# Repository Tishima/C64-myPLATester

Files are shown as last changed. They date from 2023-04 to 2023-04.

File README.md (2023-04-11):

# C64 myPLATester shield - PLA 906114-01
The myPLATester shield is a Arduino Mega shield , to test the C64 PLA 906114-01 or his clones like the GAL PAL.
It check all output vectors  via all input vectors and shows the result with a LED or serial output

Its based on the work from AC Lovell - ACs 8-Bit Zone
for more information look at his Video
https://www.youtube.com/watch?v=Yru8bx_IqN8
           
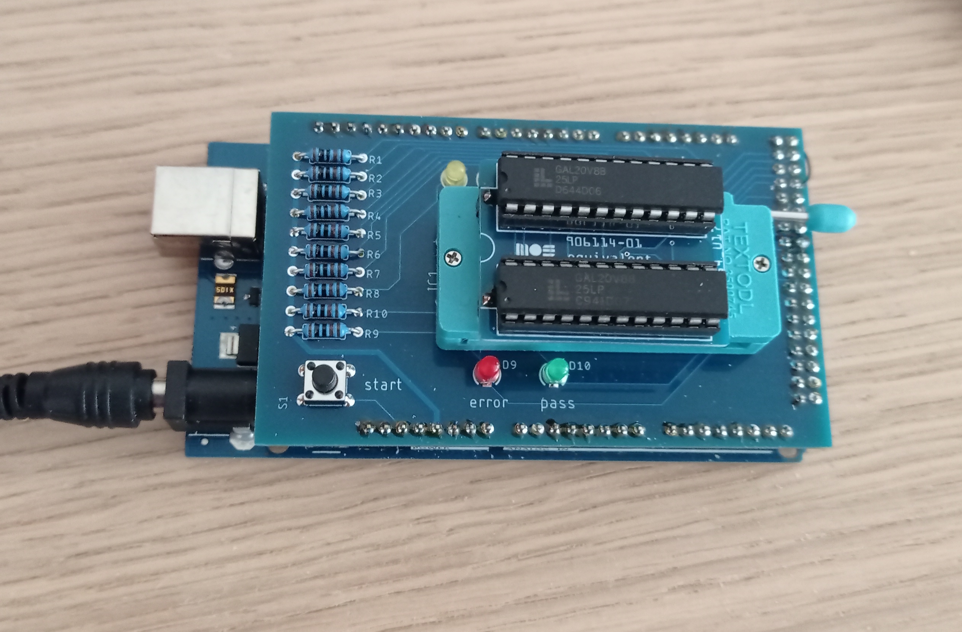
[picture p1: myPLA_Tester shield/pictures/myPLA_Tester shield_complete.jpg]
C64 myPLATester shield


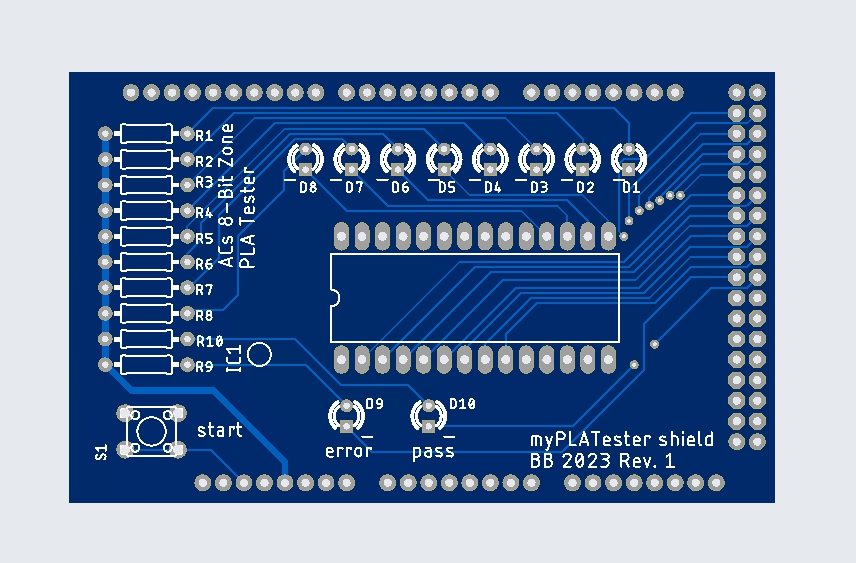
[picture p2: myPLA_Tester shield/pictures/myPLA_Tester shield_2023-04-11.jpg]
C64 myPLATester shield PCB

         
This repository contains all eagle files, gerber file, BOM, schematics, a little adjusted Arduino source code for my shield hardware, based on ACs code

Depending on where the parts and pcbs are purchased, the price for the complete shield is around 20€ (2023), without Arduino Mega and power supply
I built this project to find a issue with the GAL PLA from https://www.freepascal.org/~daniel/c64pla/, but the problem was only a wrong programming failure of my site.

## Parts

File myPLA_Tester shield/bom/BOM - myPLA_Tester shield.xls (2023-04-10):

Qty | Designator | Value | Distributor | Discription | Order Number | Price | PriceTotal | Qty count | Price count
10 | R1-R10 | 1k | Reichelt | METALL 1,00K Widerstand, Metallschicht, 1,00 kOhm, 0207, 0,6 W, 1% | METALL 1,00K | 0.11 € | 1.10 € | 10 | 1.10 €
8 | D1-D8 | LED ye | Reichelt | KBT L-7104YD LED, 3 mm, bedrahtet, gelb, 15 mcd, 40° | KBT L-7104YD | 0.15 € | 1.20 € | 8 | 1.20 €
1 | D9 | LED rd | Reichelt | KBT L-7104HD LED, 3 mm, bedrahtet, rot, 3 mcd, 40° | KBT L-7104HD | 0.14 € | 0.14 € | 1 | 0.14 €
1 | D10 | LED gr | Reichelt | KBT L-7104SGD LED, 3 mm, bedrahtet, grün, 40 mcd, 40° | KBT L-7104SGD | 0.16 € | 0.16 € | 1 | 0.16 €
2 | X1-X6 |  | Reichelt | MPE 087-1-050 Stiftleisten 2,54 mm, 1X50, gerade | MPE 087-1-050 | 0.96 € | 1.92 € | 2 | 1.92 €
1 | X7 |  | Reichelt | SL 2X36G 2,54 2x36pol.-Stiftleiste, gerade, RM 2,54 | SL 2X36G 2,54 | 0.33 € | 0.33 € | 1 | 0.33 €
1 | S1 | 3301 | Reichelt | TASTER 3301 Kurzhubtaster 6x6mm, Höhe: 4,3mm, 12V, vertikal | TASTER 3301 | 0.16 € | 0.16 € | 1 | 0.16 €
1 | IC1 |  | TME | Sockel: integrierte Schaltkreise; ZIF; DIP28; 7,62/15,24mm; THT | DS1043-280G | 4.50 € | 4.50 € | 1 | 4.50 €
1 | Arduino Mega |  | Amazon | ELEGOO Mega-R3 Mikrocontroller Board |  | 19.54 € | 19.54 € | 1 | 19.54 €
1 | PSU |  | Amazon | Netzteil für Arduino Mega, Ladegerät 9V 500mA 1000mA, Ladekabel AC DC 5,5X2,1mm |  | 9.99 € | 9.99 € | 1 | 9.99 €
 | count | 1
 | price piece | 39.04 €
 | price total | 39.04 €

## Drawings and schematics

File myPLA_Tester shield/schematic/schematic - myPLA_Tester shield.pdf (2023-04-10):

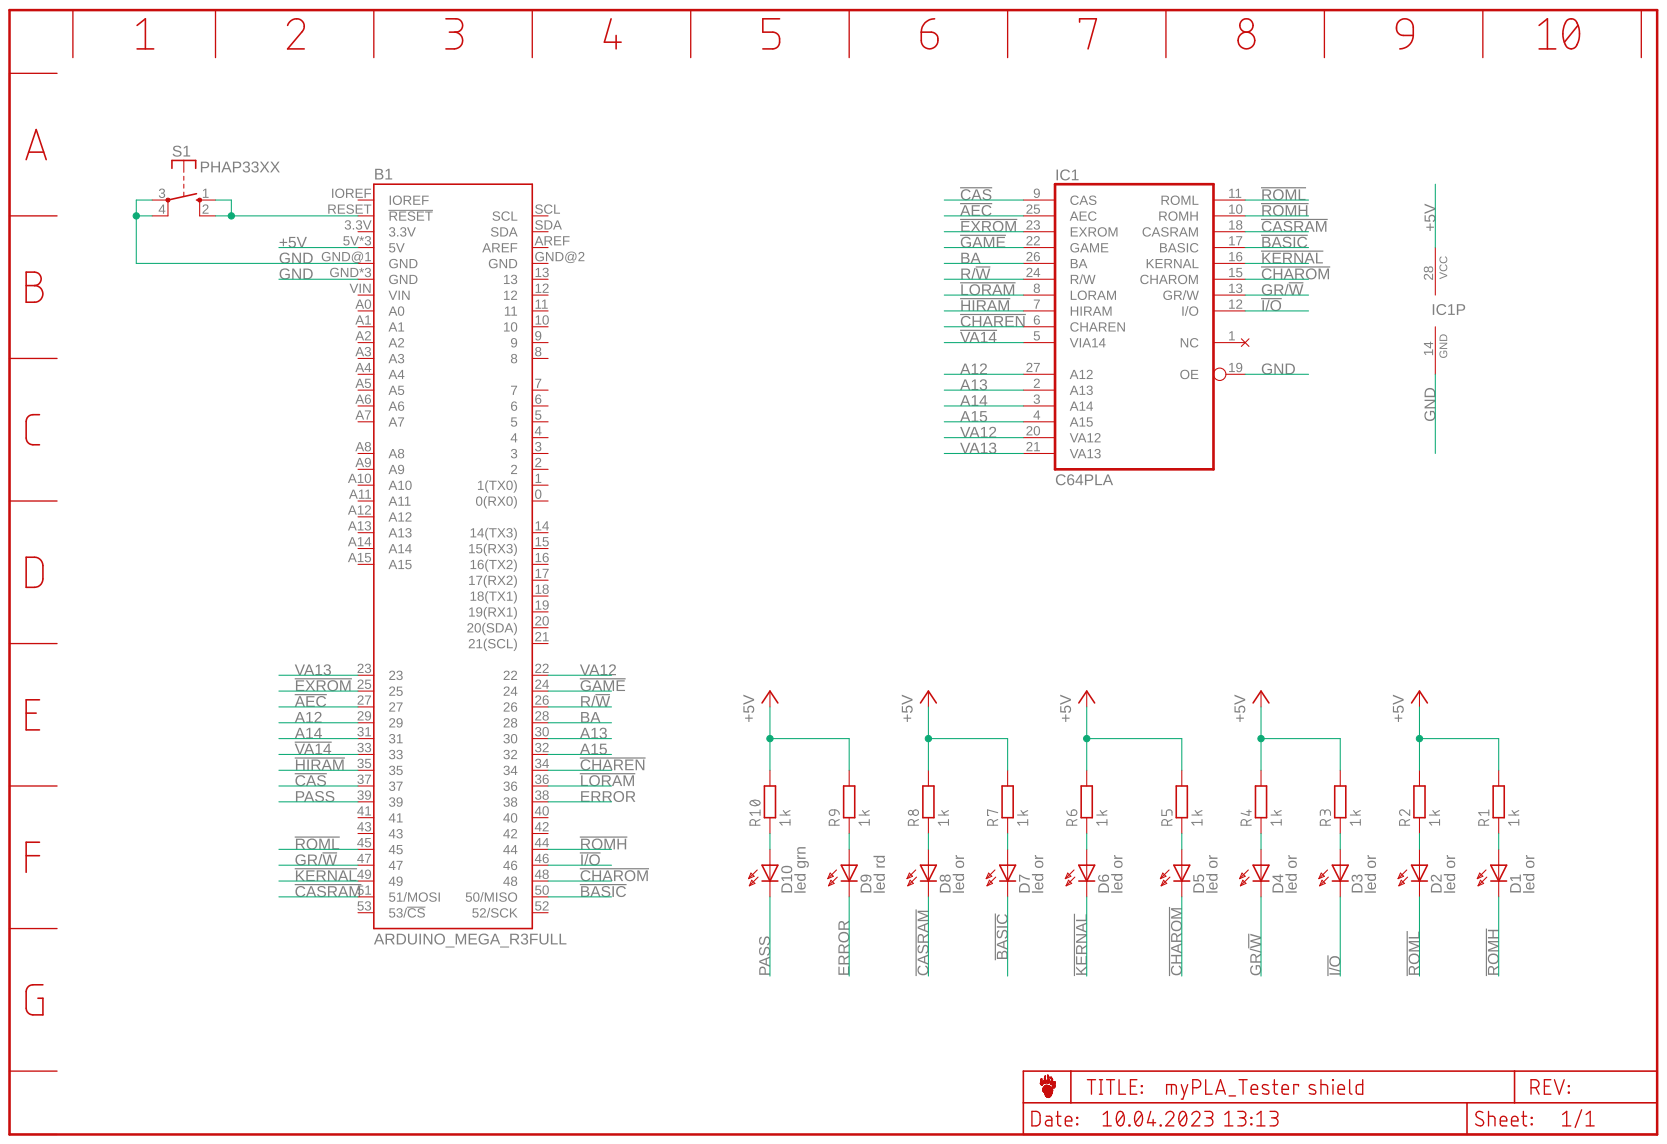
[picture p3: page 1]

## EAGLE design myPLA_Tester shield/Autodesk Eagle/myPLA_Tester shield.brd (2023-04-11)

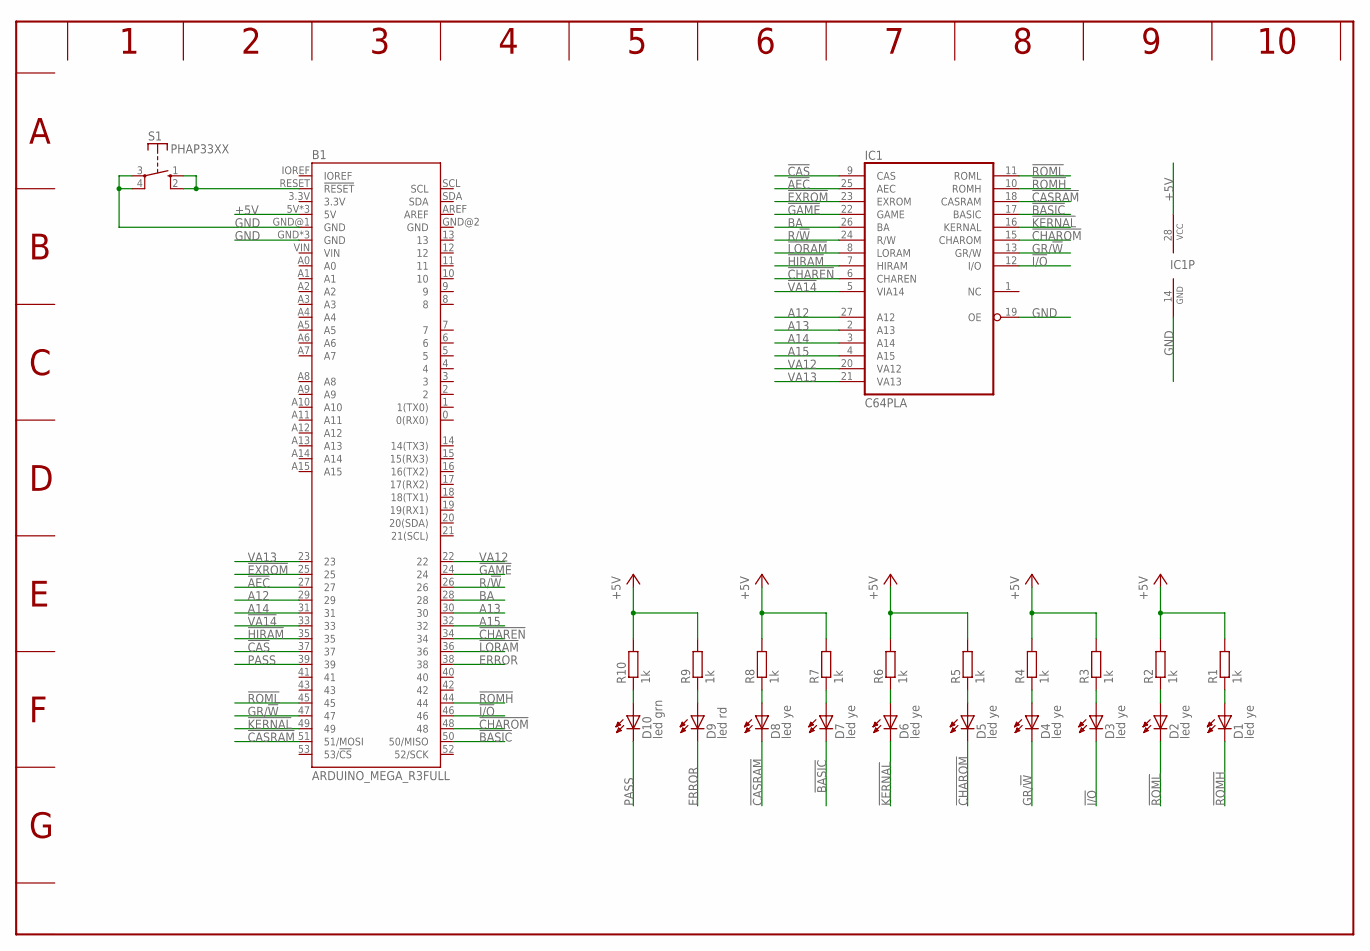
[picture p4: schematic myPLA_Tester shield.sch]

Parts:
B1: ARDUINO_MEGA_R3FULL; ARDUINO_MEGA_NO_SILK
D1, D2, D3, D4, D5, D6, D7, D8: led ye; LED3MM
D9: led rd; LED3MM
D10: led grn; LED3MM
IC1: C64PLA; DIL28
R1, R2, R3, R4, R5, R6, R7, R8, R9, R10: 1k; 0207/10
S1: PHAP33XX

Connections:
!AEC: B1.27, IC1.25 (AEC)
!BASIC: B1.50 (50/MISO), D7.K (C), IC1.17 (BASIC)
!CAS: B1.37, IC1.9 (CAS)
!CASRAM: B1.51 (51/MOSI), D8.K (C), IC1.18 (CASRAM)
!CHAREN: B1.34, IC1.6 (CHAREN)
!CHAROM: B1.48, D5.K (C), IC1.15 (CHAROM)
!EXROM: B1.25, IC1.23 (EXROM)
!GAME: B1.24, IC1.22 (GAME)
!HIRAM: B1.35, IC1.7 (HIRAM)
!I/O: B1.46, D3.K (C), IC1.12 (I/O)
!KERNAL: B1.49, D6.K (C), IC1.16 (KERNAL)
!LORAM: B1.36, IC1.8 (LORAM)
!ROMH: B1.44, D1.K (C), IC1.10 (ROMH)
!ROML: B1.45, D2.K (C), IC1.11 (ROML)
!VA14: B1.33, IC1.5 (VIA14)
+5V: B1.5V, B1.5V@1 (5V), B1.5V@2 (5V), IC1.28 (VCC), R1.2, R2.2, R3.2, R4.2, R5.2, R6.2, R7.2, R8.2, R9.2, R10.2
A12: B1.29, IC1.27 (A12)
A13: B1.30, IC1.2 (A13)
A14: B1.31, IC1.3 (A14)
A15: B1.32, IC1.4 (A15)
BA: B1.28, IC1.26 (BA)
ERROR: B1.38, D9.K (C)
GND: B1.GND, B1.GND@1 (GND), B1.GND@3 (GND), B1.GND@4 (GND), IC1.14 (GND), IC1.19 (OE), S1.3, S1.4
GR/!W: B1.47, D4.K (C), IC1.13 (GR/W)
unnamed: D2.A, R2.1
unnamed: D1.A, R1.1
unnamed: D10.A, R10.1
unnamed: D9.A, R9.1
unnamed: D8.A, R8.1
unnamed: D7.A, R7.1
unnamed: D6.A, R6.1
unnamed: D5.A, R5.1
unnamed: D4.A, R4.1
unnamed: D3.A, R3.1
unnamed: B1.RESET (!RESET), S1.1 (S), S1.2 (S)
PASS: B1.39, D10.K (C)
R/!W: B1.26, IC1.24 (R/W)
VA12: B1.22, IC1.20 (VA12)
VA13: B1.23, IC1.21 (VA13)

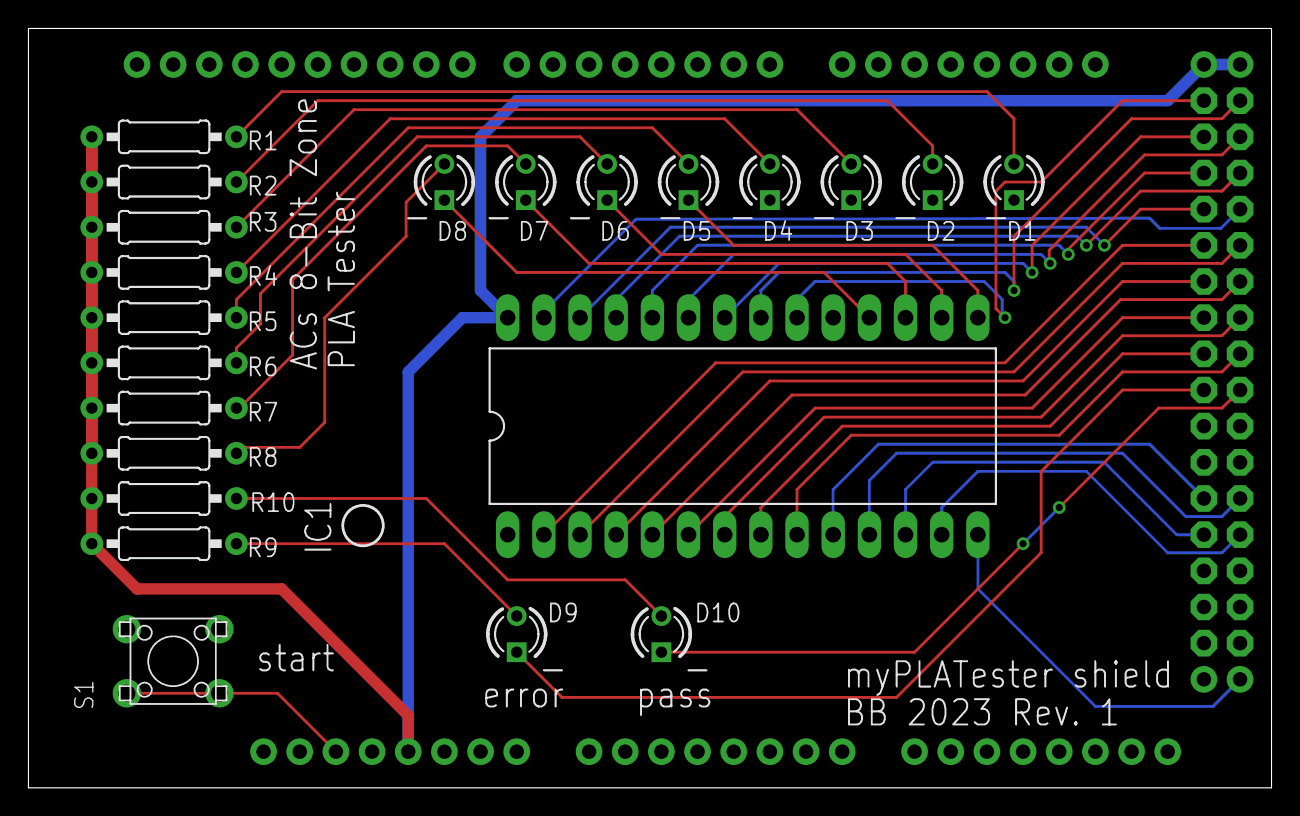
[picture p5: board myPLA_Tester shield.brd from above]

Board: 4 copper layers, 87.3 x 53.3 mm, 23 parts (0 on the bottom side), 39 nets.

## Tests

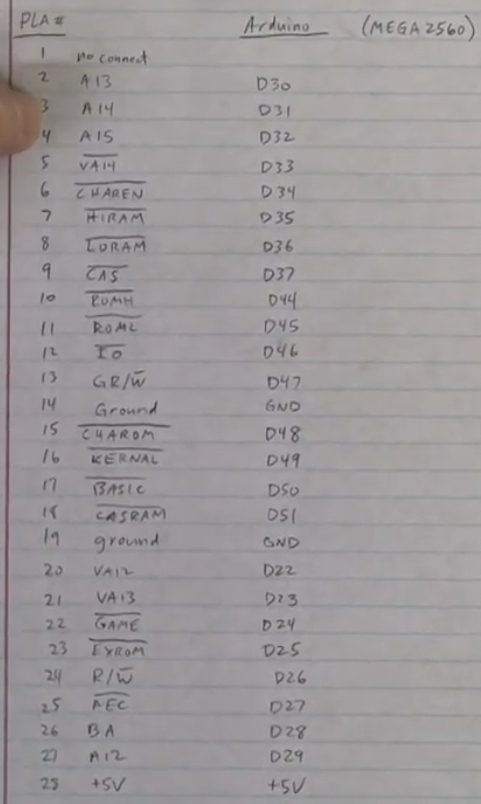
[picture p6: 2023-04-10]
myPLA_Tester shield/basics/PLATester.jpg

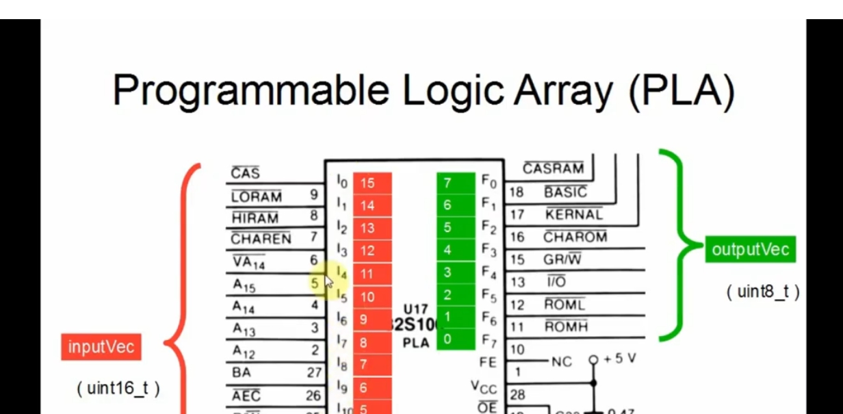
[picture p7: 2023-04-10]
myPLA_Tester shield/basics/PLATester_2.jpg

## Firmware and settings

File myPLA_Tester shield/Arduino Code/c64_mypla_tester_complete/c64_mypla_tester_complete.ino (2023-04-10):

// based on the work from AC Lovell - ACs 8-Bit Zone 10/2020
// https://www.youtube.com/watch?v=Yru8bx_IqN8
//
// some little improvements for the PLA Tester shield by Bjoern Buettner 04/2023


const bool VERBOSE = false;

uint8_t   outputVec;    // PLA outputs
uint8_t   expectedVec;  // expected PLA outputs, calculated
uint16_t  inputVec;     // PLA inputs
uint16_t  shiftReg;

char    outbuffer[120];
char    inbuffer[120];
//String  str;
//char    ch;

const uint16_t MASK[32] = {
  0x6734, 0x2734, 0x273c, 0x37b4,
  0x57b4, 0x37bc, 0x0827, 0x082f, 
  0x87b0, 0x37f4, 0x37b4, 0x57f4, 
  0x57b4, 0x37fc, 0x37bc, 0x57fc, 
  0x57bc, 0x07fc, 0x07bc, 0x6738, 
  0x072c, 0x273c, 0x072c, 0x002f, 
  0x068c, 0x070c, 0x060c, 0x070c, 
  0x078c, 0x8000, 0x8000, 0x87b0
};

const uint16_t COMP[32] = {
  0x6514, 0x2714, 0x2710, 0x2694,
  0x4694, 0x2690, 0x0825, 0x0821, 
  0x8680, 0x36d4, 0x3684, 0x56d4, 
  0x5684, 0x36d0, 0x3680, 0x56d0, 
  0x5680, 0x06d8, 0x0688, 0x6410, 
  0x0408, 0x2510, 0x0708, 0x002b, 
  0x0088, 0x0108, 0x0208, 0x0508, 
  0x0608, 0x0000, 0x8000, 0x0680
};

bool pterm[32];
long total;
long passes;

void setup() {
  // put your setup code here, to run once:

  Serial.begin(115200);
  Serial.print("Initializing test pins.\n");

  inputVec = 0xFF;

  // PLA inputs are Arduino outputs
  // We need 16 output pins
  pinMode(22, OUTPUT);
  pinMode(23, OUTPUT);
  pinMode(24, OUTPUT);
  pinMode(25, OUTPUT);
  pinMode(26, OUTPUT);
  pinMode(27, OUTPUT);
  pinMode(28, OUTPUT);
  pinMode(29, OUTPUT);
  pinMode(30, OUTPUT);
  pinMode(31, OUTPUT);
  pinMode(32, OUTPUT);
  pinMode(33, OUTPUT);
  pinMode(34, OUTPUT);
  pinMode(35, OUTPUT);
  pinMode(36, OUTPUT);
  pinMode(37, OUTPUT);

  pinMode(38, OUTPUT);     //error LED
  pinMode(39, OUTPUT);     //passe LED

  digitalWrite(38, HIGH ); // error led off
  digitalWrite(39, HIGH ); // pass led off

  digitalWrite(22, HIGH ); // 
  digitalWrite(23, HIGH ); // 
  digitalWrite(24, HIGH ); // 
  digitalWrite(25, HIGH ); // 
  digitalWrite(26, HIGH ); // 
  digitalWrite(27, HIGH ); // 
  digitalWrite(28, HIGH ); // 
  digitalWrite(29, HIGH ); // 
  digitalWrite(30, HIGH ); // 
  digitalWrite(31, HIGH ); // 
  digitalWrite(32, HIGH ); // 
  digitalWrite(33, HIGH ); // 
  digitalWrite(34, HIGH ); // 
  digitalWrite(35, HIGH ); // 
  digitalWrite(36, HIGH ); // 
  digitalWrite(37, HIGH ); // 

  // PLA outputs are Arduino inputs
  // We need 8 inputs
  outputVec = 0x00;
  pinMode(44, INPUT);
  pinMode(45, INPUT);
  pinMode(46, INPUT);
  pinMode(47, INPUT);
  pinMode(48, INPUT);
  pinMode(49, INPUT);
  pinMode(50, INPUT);
  pinMode(51, INPUT);

  passes = 0;
  total  = 0;
}


void loop() {
  // put your main code here, to run repeatedly:
  int i;
  long v; // needs to reach 65536 without rolling over

  Serial.print("Starting test. This can take up to 1 minute.\n");

  // Loop through 2^16 possible input combinations. 
  // Calculate the product terms.
  for (inputVec=0,v=0; v<65536; v++,inputVec++) {
    shiftReg = inputVec;
    // Transfer values to the pin signals D37:D22
    for (i=0; i<16; i++) {
      if (shiftReg & 0x0001) {
        digitalWrite(22+i, HIGH);
      }
      else {
        digitalWrite(22+i, LOW);
      }
      shiftReg = shiftReg >> 1;
    }
  
    // Calculate the Product terms for the set of inputVec values
    for (i=0; i<32; i++) {
      pterm[i] = ( inputVec & MASK[i] ) == COMP[i];
    }

    // Calculate the expectedVec
    expectedVec = 0x7F;
    if ( pterm[0] ) {
        expectedVec = expectedVec & 0xBF;  // clear bit 6
        expectedVec = expectedVec | 0x80;  // set bit 7
    }
      
    if ( pterm[1] || pterm[2] ) {
        expectedVec = expectedVec & 0xDF;  // clear bit 5
        expectedVec = expectedVec | 0x80;  // set bit 7
    }
      
    if ( pterm[3] || pterm[4] || pterm[5] || pterm[6] || pterm[7] ) {
        expectedVec = expectedVec & 0xEF;  // clear bit 4
        expectedVec = expectedVec | 0x80;  // set bit 7
    }
                                    
    if ( pterm[31] )
        expectedVec = expectedVec & 0xF7;  // clear bit 3
    
    if ( pterm[9] || pterm[10] || pterm[11] || 
         pterm[12] || pterm[13] || pterm[14] || 
         pterm[15] || pterm[16] || pterm[17] || pterm[18] 
    ) {
        expectedVec = expectedVec & 0xFB;  // clear bit 2
        expectedVec = expectedVec | 0x80;  // set bit 7
    }
                                    
    if ( pterm[19] || pterm[20] ) {
        expectedVec = expectedVec & 0xFD;  // clear bit 1
        expectedVec = expectedVec | 0x80;  // set bit 7
    }

    if ( pterm[21] || pterm[22] || pterm[23] ) {
        expectedVec = expectedVec & 0xFE;  // clear bit 0
        expectedVec = expectedVec | 0x80;  // set bit 7
    }
    
    if ( pterm[24] || pterm[25] || pterm[26] || 
         pterm[27] || pterm[28] || pterm[30]
    )
        expectedVec = expectedVec | 0x80;

    // Read the DUT outputs and store in outputVec.
    //Serial.print(" outputs=");
    outputVec = 0x00;
    for (i=7; i>=0; i--) {
      outputVec = outputVec << 1;
      if (digitalRead(44+i)) {
        outputVec = outputVec | 0x01;
      }
    }

    // Compare outputVec to expectedVec
    if (VERBOSE) 
    {
      sprintf(outbuffer, "inputs=%04X outputs=%02X expected=%02X\n",
                          inputVec,outputVec,expectedVec);
      Serial.print(outbuffer);
    }
    
    total=total+1;
    if ( outputVec != expectedVec ) {
      sprintf(outbuffer, "ERROR: inputs=%04X outputs=%02X expected=%02X\n",
                          inputVec,outputVec,expectedVec);
      Serial.print(outbuffer);
     break; // NOTE: comment this line to continue testing after failures
    }
    else 
      passes=passes+1;
  }

  // Done !
  Serial.println("The test is complete.");
  sprintf(outbuffer, "There were %ld passing vectors out of %ld total.", passes, total);
  Serial.println(outbuffer);

  // check passes and turn the leds on
   if (passes != 65536) {
      digitalWrite(38, LOW); // error LED on
  }
    else 
   {
      digitalWrite(39, LOW); // pass LED on
   }

  
  while(1);
}

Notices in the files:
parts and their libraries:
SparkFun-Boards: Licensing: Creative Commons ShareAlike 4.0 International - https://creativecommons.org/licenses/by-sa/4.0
